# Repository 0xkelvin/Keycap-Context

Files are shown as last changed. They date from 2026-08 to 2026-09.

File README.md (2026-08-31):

# Keycap Context

Keycap Context is an open-source, local-first four-key controller for AI coding
agents. It turns Claude Code, Codex, Gemini CLI, Antigravity, OpenCode, and
generic agent prompts into a native macOS overlay you can answer from physical
keys.

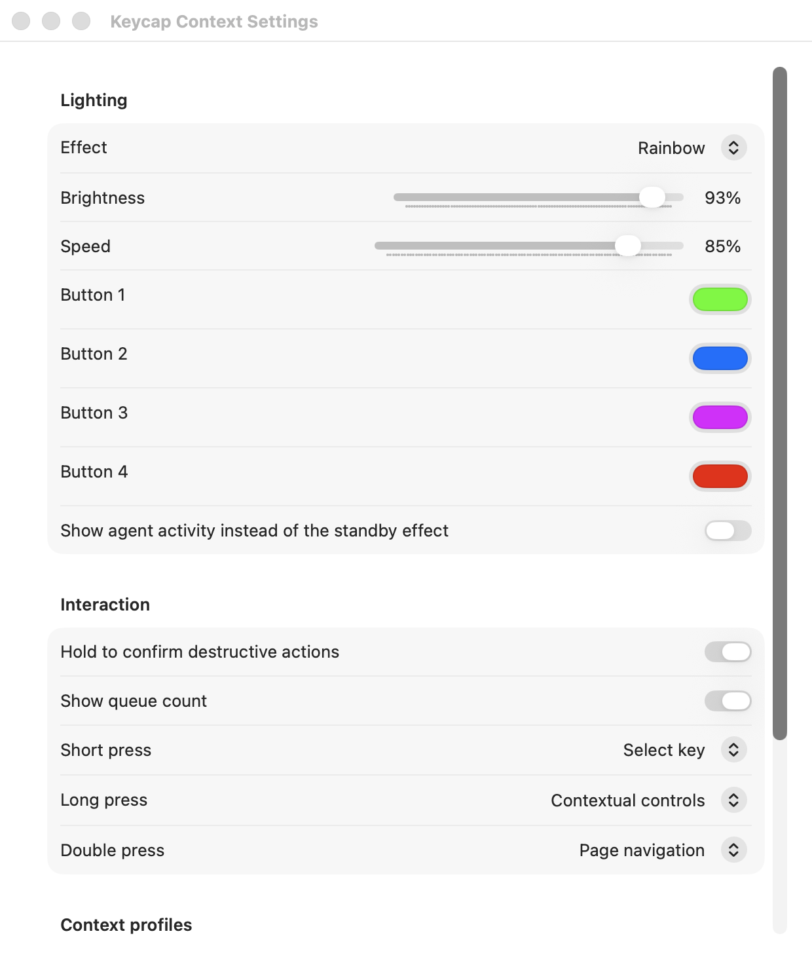
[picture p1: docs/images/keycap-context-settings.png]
Keycap Context lighting and interaction settings


## What it includes

- Zephyr firmware for a XIAO nRF54L15 Sense and Adafruit NeoKey 1x4
- Native macOS menu-bar host, choice overlay, lighting settings, and agent console
- Adapters for Claude Code, Codex, Gemini CLI, Antigravity, OpenCode, and generic JSON
- Short, long, and double-press gestures with RGB status and standby effects
- Four audio-reactive standby effects driven by the board's own microphone

## Quick start

```sh
./scripts/install.sh
```

For development without hardware:

```sh
cd host/macos
swift test
swift run keycap-host --demo
```

Firmware build:

```sh
west build -b xiao_nrf54l15/nrf54l15/cpuapp firmware
west flash
```

See [firmware setup](firmware/README.md), [architecture](docs/architecture.md),
and [adapter API](docs/http-api.md) for details.

## Hardware

Connect NeoKey `VIN/GND/SDA/SCL` to XIAO `3V3/GND/D4/D5`. Do not power NeoKey
VIN from both 3V3 and 5V.

## Privacy

The host is local-only and needs no macOS Accessibility permission. Adapters
reach it over loopback and authenticate with a per-install token.

The optional audio-reactive effects use the keypad's own microphone. Sound is
turned into four band levels on the device and drives its LEDs directly: no
audio and no derived measurement crosses the USB link, and the microphone is
left unpowered whenever another effect is selected. See [SECURITY.md](SECURITY.md).

## License

Apache-2.0

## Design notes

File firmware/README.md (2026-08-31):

# Firmware

The firmware targets the XIAO nRF54L15 Sense application core and talks to the
NeoKey's onboard seesaw controller at I2C address `0x30`.

## Build and flash

Use a recent Zephyr tree containing the XIAO nRF54L15 board definition, or the
corresponding nRF Connect SDK release:

```sh
west build -p always -b xiao_nrf54l15/nrf54l15/cpuapp firmware
west flash
```

The board's onboard SAMD11 debugger exposes the application console as a USB
CDC ACM serial port. The host opens that port at 115200 baud.

## Physical validation

1. Power the NeoKey from XIAO 3V3 and connect the common ground.
2. Connect NeoKey D/SDA to XIAO D4 and C/SCL to XIAO D5.
3. Flash firmware and open the CDC port at 115200 baud.
4. Confirm the `HELLO 3` line appears after reset.

### XIAO CMSIS-DAP serial recovery

The XIAO's onboard SAMD11 debug probe can leave its CDC serial bridge half-open
after flashing or resetting the nRF54L15: firmware output and button events
still reach the Mac, but commands sent to the board do not. The firmware then
correctly enters its amber host-watchdog state. Stop the host and fully unplug
and reconnect the board's USB cable to power-cycle the SAMD11 before testing.
If `KEEPALIVE` still does not produce `ALIVE`, diagnose or update the SAMD11
bridge rather than reflashing the nRF application repeatedly.
5. Send `LEDS FF0000,00FF00,0000FF,FFFFFF` and inspect the four pixels.
6. Press each key and confirm immediate ordered `BUTTON 1..4 DOWN`/`UP` events,
   followed by `GESTURE 1..4 SHORT`; also verify long and double presses.

## Local lighting

When no key is held, the four LEDs play a moving rainbow wave. Held keys take
immediate local priority: key 1 is green, key 2 blue, key 3 magenta, and key 4
orange. Multiple held keys light together, while unpressed keys turn off. The
local renderer refreshes at about 40 frames per second and therefore takes
visual priority over transient host LED commands.

The firmware intentionally uses the debugger's serial bridge for the first
prototype. A production PCB can expose native USB CDC from the application MCU
without changing the v1 protocol.

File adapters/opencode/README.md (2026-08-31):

# OpenCode adapter (experimental)

Install `keycap-plugin.ts` as a local OpenCode v2 plugin and add the matching
`@opencode-ai/plugin` beta dependency. It intercepts permission evaluation while
preserving OpenCode's native behavior on broker failure or overlay dismissal.
The v2 plugin API is beta, so pin the plugin package version to your OpenCode
release.

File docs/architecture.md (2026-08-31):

# Architecture

The product separates agent integrations, request policy, presentation, and
hardware. No adapter is allowed to write a number into whichever application
happens to have focus.

```text
Claude / Codex / generic CLI
            |
       agent adapter
            |
       local HTTP API
            |
     request broker/queue
       |            |
 macOS overlay   serial device
                     |
              XIAO nRF54L15
                     |
               NeoKey 1x4
```

## Request model

An adapter submits a request containing source/session metadata, the complete
question text, and one to four ordered choices. Labels and descriptions are
displayed verbatim. The broker never inserts a synthetic `Details` choice.

Only the first request is active. Later requests remain FIFO-queued. Resolving
the active request atomically removes it, replies to its adapter, and presents
the next request.

Dismissal follows the same lifecycle as a response but carries a cancellation
instead of a selected choice. The overlay's agent-specific **Handle in…** button
and its temporary Escape shortcut both cancel only the active request. Holding
Escape cannot drain the queue; the shortcut rearms after key release.

## Trust boundaries

- The HTTP listener binds only to `127.0.0.1`.
- Device input is semantic (`BUTTON 1 DOWN`), not USB HID keyboard input.
- A response is routed by request ID and cannot land in the focused editor.
- Accessibility permission is not required by the primary design.
- Escape is registered only while an overlay is visible and does not use a
  global event tap.
- Adapter content is untrusted display text and never interpreted as markup.

## Adapter levels

1. Native structured protocol: preferred for Codex App Server and agent SDKs.
2. Lifecycle hook: used by the initial Claude Code adapter.
3. Managed PTY parser: future compatibility fallback for other CLIs.

The hardware and broker API remain stable when adapters change.

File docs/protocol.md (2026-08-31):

# Device protocol

USB transport is an 8-N-1 serial stream at 115200 baud. Messages are ASCII,
newline terminated, and limited to 160 bytes. Unknown messages are ignored and
reported with `ERROR` where practical.

## Device to host

```text
HELLO 1 keycap-fw xiao-nrf54l15-sense
ALIVE
BUTTON <1..4> <DOWN|UP> <sequence>
GESTURE <1..4> <SHORT|LONG|DOUBLE> <sequence>
ERROR <code>
```

Example:

```text
BUTTON 2 DOWN 41
BUTTON 2 UP 42
```

Protocol-v1 hosts resolve a request on `BUTTON … DOWN`. Protocol-v2 firmware
emits `GESTURE` instead, after classifying short, long, and double presses.

The host resolves on `BUTTON … DOWN` only for a single-page, single-select,
non-destructive request. Paginated, multi-select, and hold-to-confirm requests
wait for the gesture so the long press that pages or confirms is not consumed
by an immediate selection.

### Framing errors

| Code | Meaning |
| --- | --- |
| `bad-command <line>` | The line did not parse as a command |
| `line-too-long` | The line exceeded 160 bytes; the tail is discarded |
| `rx-overflow` | The receive ring dropped bytes; the device resynchronizes |
| `i2c-write` | The NeoKey did not accept an LED update |
| `neokey-init` | The NeoKey is not addressable yet; the device keeps retrying |

`line-too-long` and `rx-overflow` both discard every byte up to the next
newline. A dropped newline would otherwise splice two commands into one
unparsable line, so the device forfeits one command to keep the stream framed.

## Host to device

```text
PING
KEEPALIVE
LEDS <RRGGBB>,<RRGGBB>,<RRGGBB>,<RRGGBB>
STATUS <IDLE|SUCCESS|ERROR|PAUSED>
STATUS WAITING <1..4> [RRGGBB]
LIGHTING <RAINBOW|WAVE|BREATHING|REACTIVE|AUDIO|STATIC|OFF> <0..100> <1..100> <RRGGBB,RRGGBB,RRGGBB,RRGGBB>
AGENTS <EMPTY|IDLE|WORKING|WAITING|DONE|ERROR|RISK>,<state>,<state>,<state>
```

The device replies to discovery `PING` with its `HELLO` line. After discovery,
the host sends `KEEPALIVE` every two seconds and the device replies `ALIVE`.
If acknowledgements stop for six seconds, the host first probes the existing
descriptor with `PING` and grants one further reply window. This avoids treating
a macOS sleep interval as a dead link and reopening the board's fragile
CMSIS-DAP bridge. Only an unanswered recovery probe closes the descriptor. A
later unsolicited `HELLO` requests full LED-state reinitialization.
The firmware also emits a fresh `HELLO` after the NeoKey finishes initializing.
Status or lighting commands can arrive while the I2C peripheral is still being
retried; this second handshake tells the host to replay them once the LEDs are
actually writable.
The host treats only `ALIVE` and `HELLO` as proof that the device is still
reading. Button and gesture lines are unsolicited and prove only the
device-to-host direction, so they do not refresh the liveness deadline; a link
that has gone half-open is closed and reopened instead of being held open by
key presses.
Once a serial candidate emits a valid Keycap protocol event, the host remembers
that path and does not rotate to unrelated USB modems (for example, monitor
control interfaces) after a transient heartbeat failure.

After five seconds without any valid host command, the device resumes its last
configured standalone lighting effect and repeats `HELLO` every two seconds
until the host answers. Amber is reserved for an explicit `PAUSED` status. The
first valid command clears the timeout, and the device sends one further
`HELLO` so the host re-asserts its current state.
`000000` turns a pixel off.
Color components are reduced by firmware before being written to the NeoKey to
limit brightness and USB current.

`LIGHTING` configures the device-local renderer. Brightness and speed are
percentages, and the four colors map to buttons 1 through 4. Local key-press
feedback takes visual priority over transient semantic status frames.

Protocol v3 adds `AGENTS`. Each comma-separated state maps directly to a
physical key: blue pulses while working, orange while waiting, green when work
completes, red on failure, pink for a destructive approval, dim blue for idle,
and black for an unassigned key. Approval `STATUS` frames temporarily take
priority over the agent console.

Example with three active choices:

```text
LEDS FFFFFF,FFFFFF,FFFFFF,000000
```

## Compatibility

The first integer in `HELLO` is the protocol major version. The current host
supports versions 1 through 3. Version 2 adds gestures and semantic status LEDs;
version 3 adds four-session agent states. Version 1 retains raw button events
and explicit `LEDS` commands. Hosts must
reject an unsupported major version rather than guessing message semantics.

## Audio-reactive lighting

Four effects share one capture from the board's own PDM microphone:
`LIGHTING AUDIO`, `LIGHTING SPECTRUM`, `LIGHTING PITCH` and `LIGHTING TEMPO`.

### AUDIO: level meter

`LIGHTING AUDIO` turns the four keys into a single level meter. Analysis happens entirely on the device: the keypad
reports no audio, no level and no derived measurement to the host. The link
could not carry it in any case, since 16 kHz mono PCM is roughly 32 kB/s against
a 11.5 kB/s serial budget.

The command carries no new fields. Every lit key shares one colour that walks
the rainbow wheel at `speed`, the same rate the `RAINBOW` effect uses.
`brightness` caps the meter. The four `RRGGBB` values are unused by this effect.

Loudness fills the keys as one bar, so louder sound lights more keys rather than
different ones:

| Level | Key 1 | Key 2 | Key 3 | Key 4 |
| --- | --- | --- | --- | --- |
| silence | dim ember | off | off | off |
| quiet | rising | off | off | off |
| moderate | full | rising | off | off |
| loud | full | full | rising | off |
| peak | full | full | full | full |

The meter normalises against its own rolling noise floor and peak, so it uses
the whole bar at any volume while a room's noise floor holds it nearly closed.
Rise is immediate and the fall is eased over roughly 300 ms, so it reads like a
VU needle rather than a strobe. Silence leaves the dim ember on the first key,
still cycling colour, so the device never looks dead.

### SPECTRUM: four bands, four colours

`LIGHTING SPECTRUM` gives each key its own frequency band and its own colour
from the profile, so the keys move independently and show what the music is made
of rather than how loud it is. `speed` is unused; `brightness` caps the display.

| Key | Band | Content |
| --- | --- | --- |
| 1 | up to ~170 Hz | kick and bass |
| 2 | ~170-700 Hz | body, low vocals |
| 3 | ~700 Hz-1.8 kHz | presence |
| 4 | above ~1.8 kHz | cymbals and air |

Each band normalises against its own floor and peak, so a quiet treble band does
not sit dark merely because the bass is loud. Every key keeps the same dim ember
in silence.

### PITCH: colour from content

`LIGHTING PITCH` gives all four keys one hue chosen by where the sound's energy
sits, and brightens them together with its loudness. Red is bass, green the
mids, violet the treble, so the colour reflects what the music is made of rather
than advancing on a timer. `speed` and the key colours are unused;
`brightness` caps the display.

The hue is a centroid over raw band energy with a fixed tilt, not over the
normalised band levels: per-band auto-gain drives every band to full whenever it
is near its own recent maximum, so the normalised levels reach 255 together and
preserve no balance to take a centroid of. The tilt offsets the steep falloff of
musical energy with frequency, which would otherwise pin the hue at the bass
end. Silence holds the last hue rather than snapping back to red.

### TEMPO: colour that advances with the beat

`LIGHTING TEMPO` fills the keys with loudness exactly as `AUDIO` does, but takes
its hue from the beat count rather than the clock, stepping one eighth of the
wheel on every bass transient. A full turn is eight beats, two bars of four, so
the colour returns to where it started on a musical boundary and a slow track
drifts where a fast one races. `speed` and the key colours are unused.

A beat is bass that is clear of its own noise floor, above its own rolling
average, **and rising against the previous frame**. The rise is what separates a
transient from mere loudness: a sustained bass note sits above its average for
as long as it lasts and would otherwise retrigger on every frame. Beats are
measured on raw band energy, since per-band auto-gain pins a loud passage at
full scale and leaves a kick no headroom to stand out in.

### Microphone power

The microphone is powered only while `AUDIO`, `SPECTRUM`, `PITCH` or `TEMPO` is the
selected effect and the standby lane is visible, and only while there is
something to listen to: after about ten minutes with no dynamic range in the
signal the device powers the regulator down, falls back to a dim standby
effect, and waits. Pressing any key wakes it, as does a fresh `LIGHTING`
command. A selected effect therefore holds the microphone live when music is
playing rather than for as long as the keypad is switched on.

Silence is judged as a ratio, not an absolute level: music holds its peak many
times its noise floor while a room's own noise stays within a factor of two of
it. A fixed threshold would never fire in one room and fire constantly in
another. Selecting a non-audio effect, an approval overlay, or agent
status all switch the microphone's regulator off, so an unselected microphone is
unpowered rather than merely ignored.

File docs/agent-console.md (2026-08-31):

# Agent Console

Agent Console assigns up to four recent agent sessions to the four physical
keys. Waiting sessions are protected from replacement; when all slots are full,
the oldest idle or completed session is replaced first.

## States

Settings defaults to the selected four-key standby lighting effect. Enable
**Show agent activity instead of the standby effect** to display these states
on protocol-v3 hardware while no approval overlay is visible.

| State | LED | Meaning |
| --- | --- | --- |
| Working | Pulsing blue | Agent is reasoning or executing tools |
| Waiting | Pulsing orange | Agent needs a decision |
| Destructive | Pulsing pink | Decision can modify or remove data |
| Completed | Green | Completed activity has not been acknowledged |
| Failed | Pulsing red | Agent or tool failed |
| Idle | Dim blue | Session is assigned but inactive |

The menu-bar **Agent Console…** window shows source, project, current state,
focus/interrupt/resume/cancel controls, and the last 500 local status, approval,
resolution, and control events. The history contains summaries—not secrets or
complete terminal transcripts—and is stored in Application Support.

Persistent adapters drain control commands from the local HTTP API. The Codex
App Server bridge maps interrupt/cancel to its native `turn/interrupt` request.
Hook-only adapters receive the status and approval features but cannot interrupt
a tool that is already running; the command remains available to a future
persistent bridge.

## Context profiles

When a key has no assigned agent, a short press may execute the first profile
matching the frontmost application's bundle identifier and project rule.
Actions can focus or interrupt an agent, open an HTTP(S) URL, or run a local
shell command. Interrupts and shell commands always require confirmation.
Settings renders the four actions before assignment so workflows can be
reviewed without executing them.

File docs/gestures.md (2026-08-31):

# Hardware gestures

Firmware protocol v2 delays a short press for 280 ms so it can distinguish a
double press. A long press fires after 600 ms. Holding a key produces one event.

| Gesture | Action |
| --- | --- |
| Short press 1–4 | Select the visible choice, or toggle it in multi-select |
| Double press 1 | Previous page |
| Double press 4 | Next page |
| Long press 1 | Previous page |
| Long press 2 | Clear multi-select choices |
| Long press 3 | Hand the request back to the agent |
| Long press 4 | Submit multi-select, otherwise next page |

When no approval overlay is visible, protocol-v3 keys control their assigned
agent session:

| Gesture | Agent-console action |
| --- | --- |
| Short press | Focus the originating terminal application |
| Long press | Request an interrupt and cancel any queued approval |
| Double press | Mark completed work as read |

Agent focus begins immediately on the first physical button-down, before the
280 ms gesture-classification window. The later short event is consumed; a
continued hold or second press still performs its long/double action. On a
multi-monitor Mac, focusing raises the terminal's most recently used window on
the display where that window already lives—it does not move windows between
displays.

Single-page, single-choice approval overlays resolve from the debounced
`BUTTON DOWN` event immediately. The delayed gesture event is consumed by the
host so it cannot affect the next queued overlay or an Agent Console assignment.
Paginated, multi-select, and destructive hold-to-confirm requests wait for the
gesture instead, because an immediate selection would consume the long press
that pages or confirms.

Protocol-v1 firmware remains compatible and resolves on `BUTTON … DOWN`.

LED states are semantic in protocol v2: dim blue is idle, agent-colored keys
are waiting choices, green is success, red is error, and amber is paused. If no
host command arrives for five seconds, firmware resumes the last standalone
lighting effect while continuing to advertise for reconnection.

Protocol-v3 idle LEDs run the selected standby lighting effect by default.
Settings can instead show agent state: blue working, orange waiting, green
completed, red failed, pink destructive approval, dim blue idle, and off when
no session is assigned.

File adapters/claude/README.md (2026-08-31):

# Claude Code adapter

The adapter uses two documented Claude Code lifecycle hooks:

- `PermissionRequest` for allow/always-allow/deny decisions
- `PreToolUse` filtered to `AskUserQuestion` for exact multiple-choice input
- `PreToolUse` filtered to `ExitPlanMode` for plan approval

The hook posts to the local broker and blocks until a physical or overlay
selection resolves the request. If the broker cannot be reached, it emits no
decision and Claude retains its normal terminal interaction.

Choose **Handle in Claude** in the overlay or press Escape to dismiss the active
request without making a selection. The broker releases the waiting hook, which
emits no decision so Claude presents its normal terminal interaction.

`AskUserQuestion` is excluded from the generic `PermissionRequest` bridge. This
prevents Claude's raw question payload from being queued as a second permission
overlay after a question is handed back to the terminal.

## Configure

1. Start `keycap-host`.
2. Copy the entries in `settings.fragment.json` into the existing `hooks`
   object in `~/.claude/settings.json`.
3. Replace `/ABSOLUTE/PATH/TO` with this repository's absolute path.
4. Run `/hooks` in Claude Code and verify both entries.

Do not replace an existing `hooks` object wholesale. Merge the two event arrays
with any hooks already configured.

Single-choice, multi-select, and batches of several questions are supported.
Multi-select uses an explicit Submit button in the overlay; protocol-v2 hardware
uses a long press on key 4 to submit.

## How an answered question is returned

The hook allows the call with the answers filled into `updatedInput`.
`AskUserQuestion` honours a pre-filled `answers` field and returns it without
prompting, so the question is not asked again in the terminal.

Handing the overlay back instead returns nothing at all, which lets Claude Code
prompt in the terminal as usual.

Denying the call and carrying the answers in `permissionDecisionReason` also
works, but Claude Code renders a blocked call as an error, which reads like a
failure. Measured against a live broker, the allowed call returns in the same
second the keypad resolves the overlay; a terminal prompt instead shows up as a
gap of tens of seconds.

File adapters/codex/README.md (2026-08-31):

# Codex adapter

The initial adapter uses Codex's documented `PermissionRequest` lifecycle hook.
It displays the tool description and complete JSON input, then offers the two
decisions the hook API can currently return safely: Allow and Deny.

## Configure

1. Start `keycap-host`.
2. Merge `hooks.fragment.json` into `~/.codex/hooks.json` and replace the
   absolute-path placeholder.
3. Open `/hooks` in Codex and explicitly review/trust the new hook.

If the broker is unavailable, the hook emits no decision and Codex presents
its normal terminal approval prompt.

Choose **Handle in Codex** in the overlay or press Escape to dismiss the active
request without making a selection. The hook emits no decision, returning the
approval to Codex's terminal UI.

## Rich adapter

`app_server_bridge.py` is a transparent stdio proxy for clients that normally
launch `codex app-server`. Configure the client to launch:

```sh
python3 /ABSOLUTE/PATH/TO/adapters/codex/app_server_bridge.py codex app-server
```

The proxy routes command and file approvals—including `acceptForSession`—and
`item/tool/requestUserInput` through Keycap. If the user chooses **Handle in
Codex**, the original server request is forwarded to the parent client so its
normal UI remains authoritative. Secret and free-form questions also pass
through unchanged.

The bridge uses the App Server schema generated by the installed Codex version;
WebSocket transport remains experimental upstream and is intentionally outside
this stdio proxy.

The hook does not invent an Always Allow option because Codex currently rejects
permission updates from `PermissionRequest` hooks.

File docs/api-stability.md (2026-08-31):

# API stability

The loopback broker API is versioned under `/v1`. Additive JSON fields are
allowed within v1; existing fields, response meanings, and HTTP lifecycle
semantics are stable. Breaking changes require a new path such as `/v2`.

Device protocol major versions are announced by `HELLO`. The host supports
majors 1 and 2 and must reject unknown majors. New optional commands may be
added to protocol 2, but existing command grammar and gesture meanings remain
stable.

Settings use a `schemaVersion`. Unknown or malformed settings fall back to safe
defaults, while the previous valid file is retained as `settings.json.previous`.
Adapters must preserve the native agent UI whenever the broker is unavailable,
returns cancellation, or rejects a request.

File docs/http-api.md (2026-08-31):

# Local HTTP API

Keycap Context listens only on `127.0.0.1`. The default port is `47821`; set
`KEYCAP_PORT` or pass `--port` to the host, and set `KEYCAP_BROKER_URL` in
adapters when using a different port.

## Authentication

Loopback binding proves only that the caller is on this machine. It does not
distinguish a trusted adapter from any other local process, nor from a web page
the user is visiting: a CORS-simple `POST` from a page reaches the broker with a
loopback `Host` header like any other client. Every request is therefore
authenticated.

On first launch the host writes a 32-byte random token, owner-readable only, to
`~/Library/Application Support/Keycap Context/token` (override with
`KEYCAP_TOKEN_PATH`). Adapters present it as `Authorization: Bearer <token>` or
`X-Keycap-Token: <token>`; the bundled adapters read the file automatically, and
`KEYCAP_TOKEN` overrides it.

This secret protects against other machine accounts and, together with the
fetch-metadata checks, browser pages. It is not a sandbox boundary against an
untrusted process already running as the same macOS user: that process can read
the same owner-readable token as an adapter.

```sh
curl -s -H "Authorization: Bearer $(cat ~/Library/Application\ Support/Keycap\ Context/token)" \
  http://127.0.0.1:47821/health
```

The broker answers `401 Unauthorized` for a missing or wrong token and `403
Forbidden` for a non-loopback `Host` header or for any request carrying browser
fetch metadata (`Origin`, or `Sec-Fetch-Site` other than `none`). Adapters treat
both as "broker unavailable" and fall back to the agent's own terminal prompt,
so a stale token degrades safely rather than blocking an agent.

## Endpoints

- `GET /health` returns broker, queue, pause, agent, and device health.
- `GET /v1/capabilities` reports API and device protocol capabilities.
- `POST /v1/requests/wait` submits an `AgentRequest` and holds the response
  until it is selected or cancelled.
- `DELETE /v1/requests/{id}` cancels one pending request.
- `POST /v1/sessions/cancel` with `{"session":"..."}` cancels all requests
  owned by a session.
- `POST /v1/sessions/status` reports `working`, `waiting`, `completed`, `failed`,
  or `idle` activity for a session.
- `GET /v1/sessions` returns the persistent four-key session assignments.
- `DELETE /v1/sessions/{session}` unassigns a session from its physical key.
- `POST /v1/sessions/control` queues `focus`, `interrupt`, `resume`, `cancel`,
  or `markRead` for a session.
- `GET /v1/sessions/{session}/commands` atomically drains pending controls for
  a persistent adapter bridge.
- `GET /v1/history` returns the bounded local approval/control audit history.

The broker rejects malformed requests with `422`, duplicate IDs with `409`,
new requests while paused with `503`, and requests beyond the 64-entry queue
limit with `429`. A disconnected waiting client is
removed from the queue automatically.

The server authenticates every request, validates the HTTP `Host` header as
loopback-only, refuses browser-originated requests, and bounds request and field
sizes before presentation.

Requests support one to sixteen choices, optional `allowsMultiple`, optional
`progress` (`current` and `total`), optional `timeoutSeconds`, and an optional
six-digit `accentColor`. Multi-select responses include ordered `choiceIds`;
single-select responses retain the backward-compatible `choiceId` field.
Requests may set `risk` to `destructive` to activate hold-to-confirm behavior.
Requests may also provide `clientApp`, a macOS bundle identifier used only to
focus the originating terminal. The host never accepts remote network clients.

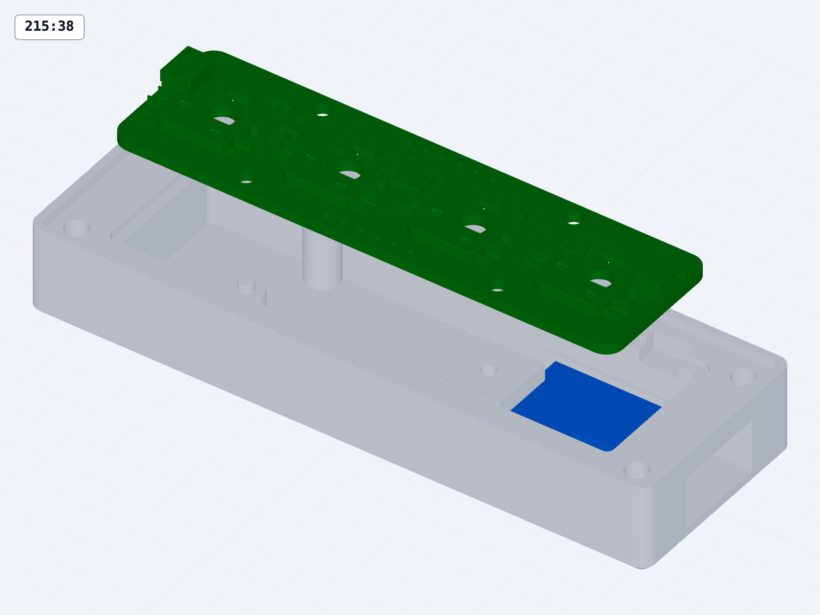
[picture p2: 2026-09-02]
cad/renders/09-boards-in-tray.png

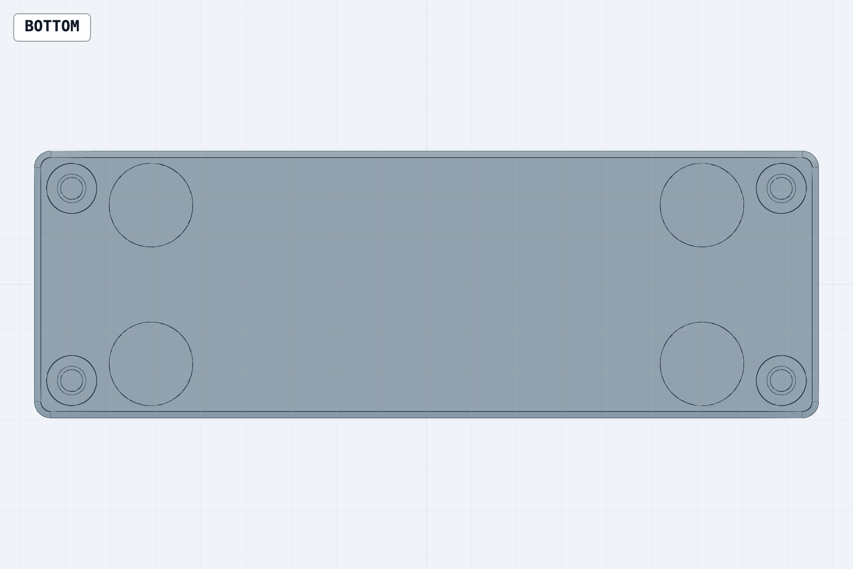
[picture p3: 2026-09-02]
cad/renders/05-underside.png

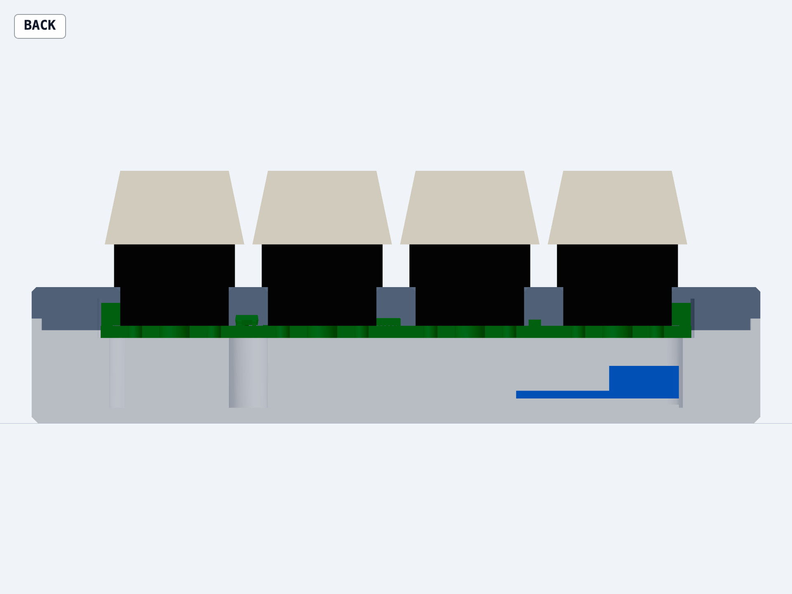
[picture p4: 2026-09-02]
cad/renders/07-cutaway-section.png

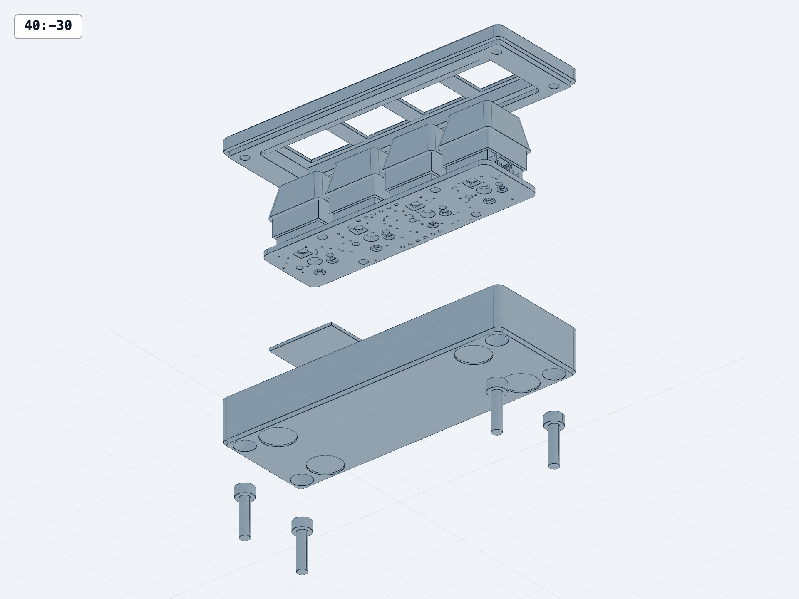
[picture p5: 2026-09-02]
cad/renders/11-plate-underside.png

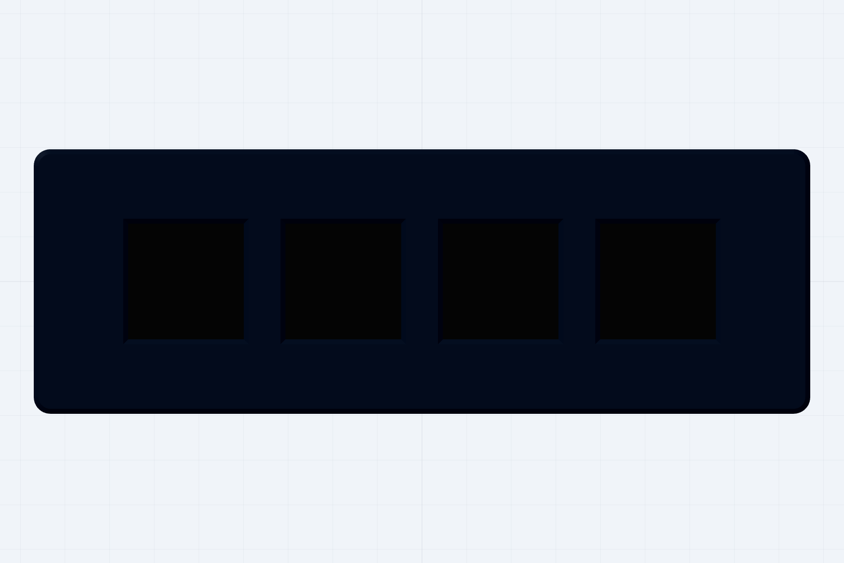
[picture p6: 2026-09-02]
cad/renders/03-plate-top.png

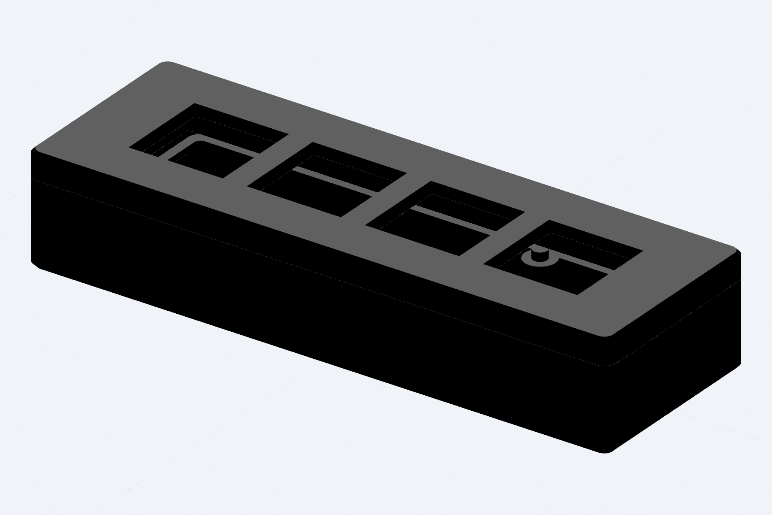
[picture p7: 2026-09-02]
cad/renders/colourways/ink.png

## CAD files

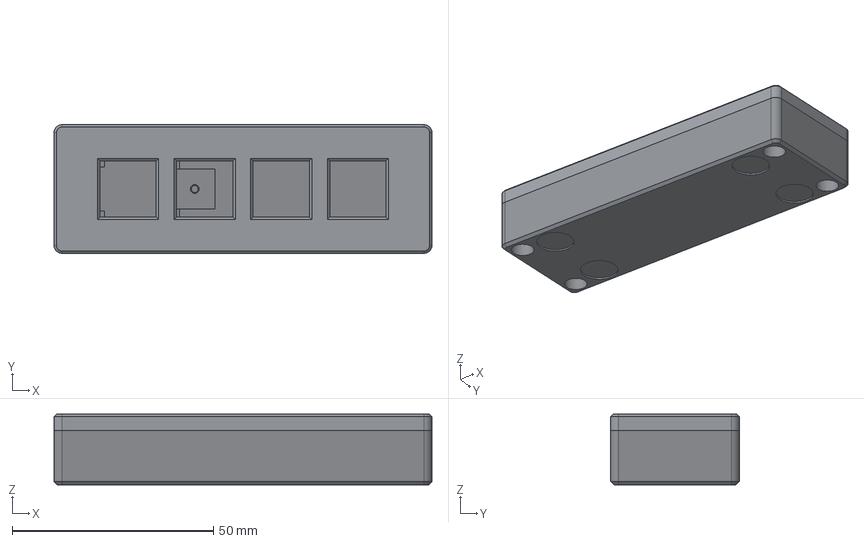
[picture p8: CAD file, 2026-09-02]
cad/keycap_case.step
94.0 x 32.0 x 17.6 mm
tray
plate
xiao_clamp

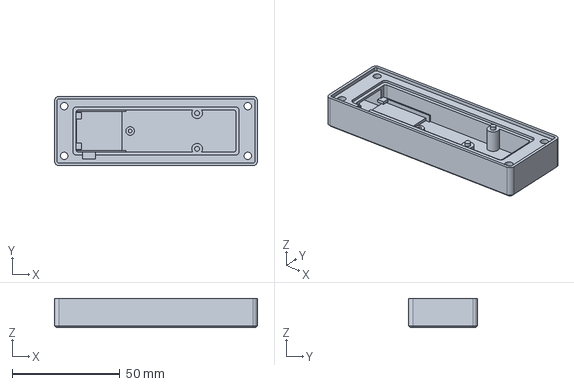
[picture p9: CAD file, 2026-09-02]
cad/print/tray.step
94.0 x 32.0 x 13.5 mm

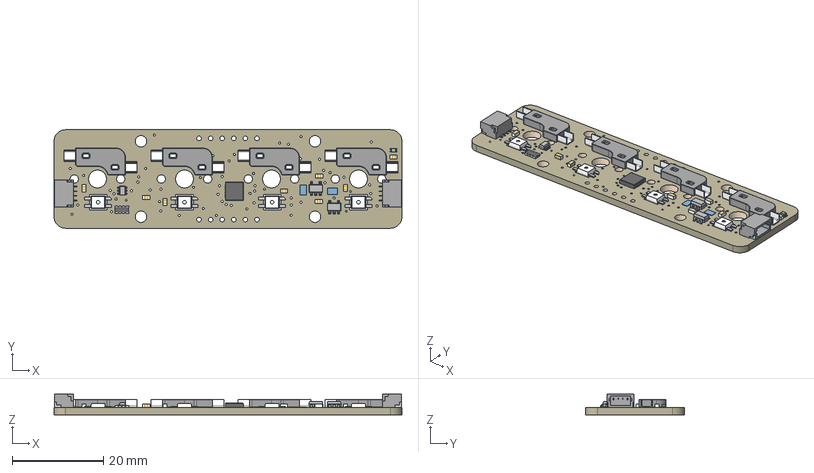
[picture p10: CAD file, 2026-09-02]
cad/reference/neokey_1x4_qt_4980.step
76.2 x 21.6 x 4.53 mm
Board
KAILH_SOCKET x 4
WS2812B_SK6812E x 4
10K x 8
10uF x 2
AP2112K-3.3
10K_1
BSS138
STEMMA_I2C_QT x 2
GREEN
ATSAMD09D14A-MU
74AHCT1G125DBV

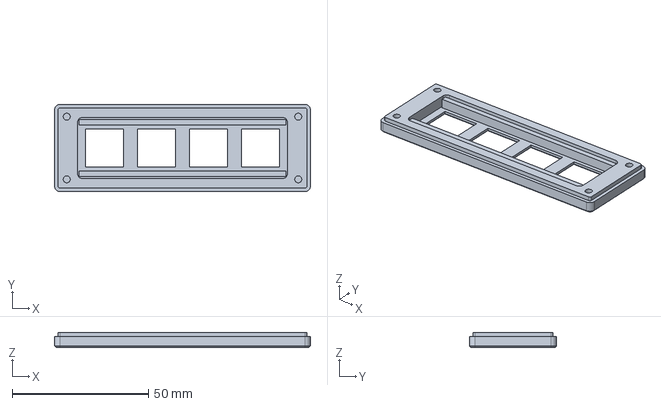
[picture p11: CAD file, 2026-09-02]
cad/print/plate.step
94.0 x 32.0 x 5.57 mm

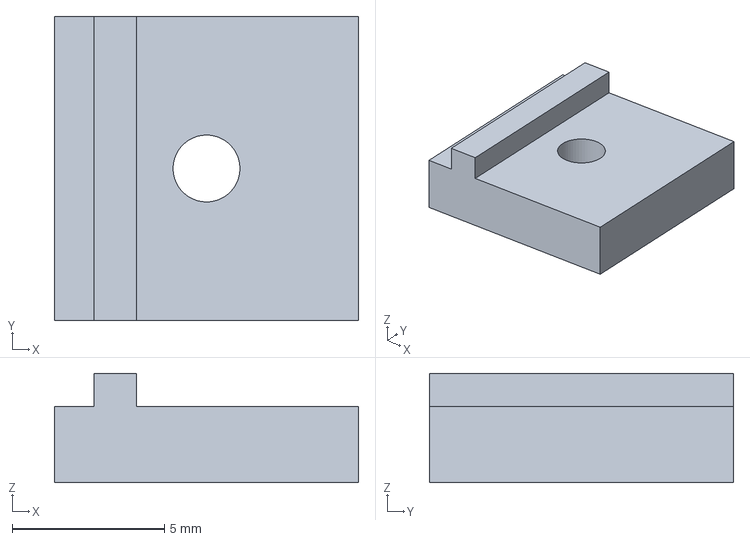
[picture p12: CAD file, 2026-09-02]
cad/print/xiao_clamp.step
10.0 x 10.0 x 3.60 mm

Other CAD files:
cad/print/stl/plate.3mf
cad/print/stl/plate.stl
cad/print/stl/tray.3mf
cad/print/stl/tray.stl
cad/print/stl/xiao_clamp.3mf
cad/print/stl/xiao_clamp.stl

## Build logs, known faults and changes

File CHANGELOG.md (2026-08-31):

# Changelog

## Unreleased

### Added

- Added an `AUDIO` lighting effect: the four keys become one level meter driven
  by the board's PDM microphone, sharing a single colour that cycles the rainbow
  at the profile speed. Loudness fills the keys in order, normalised against a
  rolling noise floor so the whole bar is used at any volume, with an immediate
  rise, an eased fall, and a dim ember left on the first key in silence.
  Analysis runs entirely on the device; no audio or derived measurement crosses
  the serial link, and the microphone's regulator is switched off whenever
  neither audio effect is selected.
- Added a `SPECTRUM` lighting effect sharing the same capture: each key takes
  its own frequency band and its own colour, bass on key one through treble on
  key four, with each band normalised independently.
- Added a `PITCH` lighting effect sharing the same capture: all four keys take
  one hue from where the sound's energy sits, red for bass through violet for
  treble, brightening together with loudness. The hue holds through silence
  rather than resetting between tracks.
- Raised the NeoKey I2C bus to fast mode, quartering the time the main loop
  spends blocking on each LED frame.

- The microphone now sleeps after about ten minutes with nothing playing: the
  regulator is switched off, the keys fall back to a dim standby effect, and a
  key press wakes it. Silence is judged by how little dynamic range the signal
  has relative to its own noise floor, so the test does not depend on a room's
  absolute noise level.

- Added a `TEMPO` lighting effect: the level meter with a colour that steps one
  eighth of the wheel on every bass transient, so the palette advances with the
  music rather than with a clock.

- The overlay now says which gesture finishes the request. Multi-select shows
  how to submit and clear, and a paginated request how to page, alongside the
  hold-to-confirm hint destructive requests already had. The hints follow the
  configured gesture mapping, so a remapped long press earns no hint rather
  than a wrong one.

### Fixed

- `keycap_audio_analyzer_init` cleared only its channels, leaving the beat
  count, hue, quiet countdown and bass history holding whatever was previously
  on the audio thread's stack.

- A short press on an assigned key no longer re-activates its terminal when that
  terminal is already frontmost. This was the cause of questions appearing to
  repeat: each activation redraws whatever prompt the terminal is showing, and
  an audio effect invites exactly the run of presses that triggers it.

- An unrecognised lighting effect in the settings file no longer discards every
  other preference. A strict decoder failed the whole file, so a host without a
  newer effect silently reverted brightness, colours, gestures and profiles to
  their defaults.

### Fixed

- A slow NeoKey/I2C startup no longer leaves all four LEDs stuck on the amber
  paused frame. The firmware announces itself again after LED initialization,
  causing the host to replay status and the selected standby lighting profile.
- Serial configuration failures now close their file descriptor, and stale
  immediate-press gesture state is cleared across device reconnects.
- Serial autodetection now rotates through every USB modem candidate after a
  failed handshake instead of retrying the same unrelated debug port forever.
- Malformed persisted lighting values are normalized before the four-key
  settings UI reads them, avoiding an out-of-range crash on edited settings.
- Idle agent switching now focuses on the initial button-down instead of after
  the double-press delay, and no longer raises every terminal window across a
  multi-monitor desktop.
- The macOS serial host now clears inherited modem/flow-control flags and
  flushes stale bytes before discovery. A CMSIS-DAP port could otherwise remain
  half-open: buttons reached the host, but lighting and heartbeat commands did
  not reach the board. Device health now becomes connected only after a valid
  firmware `HELLO`, so an LG monitor-control modem cannot report as a Keycap.
- After any valid Keycap event, serial discovery now remains affined to that
  device and will not rotate onto an external monitor's control modem during a
  one-way CMSIS-DAP bridge failure.
- Wake recovery now probes the existing serial descriptor before closing it,
  avoiding the SAMD11 reopen path that wedges after macOS sleep. If the host is
  unavailable, firmware continues the last standby effect instead of latching
  all four LEDs amber.
- Reinstalling or packaging now replaces adapter directories instead of
  merging stale files, and excludes generated Python caches and test fixtures.
- Multi-select requests now offer a Submit control. The button had been placed
  in the hold-to-confirm branch, so a multi-select question could only be
  answered with a hardware long press, and destructive requests showed a
  redundant disabled `Submit 0` beside `Confirm selection`.
- Paginated single-select requests no longer resolve from `BUTTON … DOWN`. The
  immediate press consumed the long press that pages, so requests with five to
  sixteen choices exposed only their first four options on hardware.
- The firmware resynchronizes the serial stream after the receive ring drops
  bytes, and keeps draining the ring while the NeoKey is still initializing.
  Blocking retries had overflowed the ring and spliced host commands together
  (`PING` + `PING` arriving as `PIPING`).
- Overlay choices accept the first mouse click while another application is
  frontmost.
- The keys no longer stay amber after the host watchdog fires. The fail-safe
  had latched the flag that suppresses the standby effect, and only a `STATUS`
  command cleared it -- which the host sends on state changes only, so a
  recovered link stayed amber until the board was unplugged.
- The device repeats `HELLO` every two seconds while the host is unreachable.
  The single announcement was emitted during the outage that triggered it, so
  losing that one line left both sides waiting for each other.
- Added `keycap_console_ready` and `keycap_serial_error` beside the existing
  `keycap_neokey_status` probe word, so a board whose console never comes up can
  still report where bring-up stopped over SWD.
- A failed console bring-up no longer ends `main()`. Returning left the device
  permanently silent with the NeoKey holding its last frame, recoverable only by
  a power cycle; the device now retries until the console is ready.
- The host no longer treats unsolicited button and gesture traffic as proof the
  device is still listening. Only replies to its own `PING`/`KEEPALIVE` count,
  so a half-open link is now detected and reconnected within six seconds
  instead of being held open by the user pressing keys.

### Security

- The local HTTP API authenticates every request with a per-install token
  written owner-readable to Application Support, and refuses requests carrying
  browser fetch metadata. A loopback `Host` header alone had been sufficient to
  read the approval history or raise a spoofed approval overlay.
- Token permission changes now fail closed, browser `Origin: null` requests are
  rejected, and the installer refuses unsafe root/home removal targets.

### Added

- Added the Agent Console with four persistent agent/session slots, status LEDs,
  terminal focus, interrupts, resume/cancel commands, and local audit history.
- Added protocol v3 `AGENTS` rendering and two additional firmware Ztests.
- Added firmware framing tests and a CI job that runs the Zephyr ztests.
- Added an Antigravity CLI plugin with native fallback and lifecycle reporting.
- Added context-aware application/project profiles and workflow preview.
- Added session status, control, command-polling, session-list, and history APIs.
- Added persisted lighting profiles and a macOS settings window.
- Added rainbow, wave, breathing, reactive, static, and off lighting modes.
- Added adjustable brightness, speed, and per-key colors.
- Added hold-to-confirm behavior for requests marked destructive.
- Added a diagnostics export and connected firmware/protocol information.

## 0.4.0

- Added protocol-v2 gestures, semantic LEDs, richer Codex/Claude adapters,
  cancellation cleanup, pagination, multi-select, installer, and CI.

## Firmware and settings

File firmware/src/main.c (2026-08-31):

/* SPDX-License-Identifier: Apache-2.0 */
#include "neokey.h"
#include "protocol.h"
#include "gesture.h"
#include "lighting.h"
#include "line_reader.h"
#include "audio.h"

#include <errno.h>
#include <string.h>
#include <zephyr/device.h>
#include <zephyr/devicetree.h>
#include <zephyr/drivers/uart.h>
#include <zephyr/irq.h>
#include <zephyr/kernel.h>
#include <zephyr/sys/ring_buffer.h>

#define NEOKEY_ADDRESS 0x30
#define DEBOUNCE_SAMPLES 2
#define HOST_WATCHDOG_MS 5000u
#define HOST_HELLO_RETRY_MS 2000u
#define NEOKEY_RETRY_SLICE_MS 50u
#define NEOKEY_RETRY_SLICES 20u

static const struct device *const console = DEVICE_DT_GET(DT_CHOSEN(zephyr_console));
static const struct device *const i2c = DEVICE_DT_GET(DT_ALIAS(neokey_i2c));
RING_BUF_DECLARE(serial_rx, 512);

/* Set from the receive interrupt when the ring cannot hold an incoming chunk.
 * The dropped bytes may include a newline, so the main loop must discard the
 * damaged region rather than parse two spliced commands as one.
 */
static volatile bool serial_rx_overflow;
static struct keycap_line_reader line_reader;

/* Set once the microphone has been powered down for want of anything to
 * listen to. Cleared by a key press or by the host changing the lighting.
 */
static bool audio_asleep;

/* Kept visible for probe-based bring-up and field diagnostics.
 *
 * When the console does not come up there is no way to report a fault, so
 * bring-up state is recorded in RAM where a debugger can read it:
 *
 *   arm-zephyr-eabi-nm build/zephyr/zephyr.elf | grep keycap_
 *   openocd ... -c "halt" -c "mdw <address> 1" -c "resume"
 *
 * keycap_console_ready  1 once the console device reports ready
 * keycap_serial_error   0 once the receive callback is installed
 * keycap_neokey_status  0 once the NeoKey answers on I2C
 */
volatile int keycap_neokey_status = -EINPROGRESS;
volatile int keycap_console_ready = -1;
volatile int keycap_serial_error = -EINPROGRESS;

static void serial_rx_callback(const struct device *device, void *user_data)
{
	ARG_UNUSED(user_data);
	uint8_t bytes[32];

	uart_irq_update(device);
	if (!uart_irq_rx_ready(device)) {
		return;
	}

	int count;
	while ((count = uart_fifo_read(device, bytes, sizeof(bytes))) > 0) {
		if (ring_buf_put(&serial_rx, bytes, (uint32_t)count) <
		    (uint32_t)count) {
			serial_rx_overflow = true;
		}
	}
}

static bool take_rx_overflow(void)
{
	unsigned int key = irq_lock();
	bool overflowed = serial_rx_overflow;

	serial_rx_overflow = false;
	irq_unlock(key);
	return overflowed;
}

static int serial_rx_start(void)
{
	keycap_console_ready = device_is_ready(console) ? 1 : 0;
	if (keycap_console_ready != 1) {
		return -ENODEV;
	}

	int error = uart_irq_callback_user_data_set(console, serial_rx_callback, NULL);
	keycap_serial_error = error;
	if (error != 0) {
		return error;
	}
	uart_irq_rx_enable(console);
	return 0;
}

static void serial_write(const char *text)
{
	while (*text != '\0') {
		uart_poll_out(console, *text++);
	}
}

static void send_hello(void)
{
	serial_write("HELLO 3 keycap-fw xiao-nrf54l15-sense\n");
}

static int show_status(struct neokey *keys, enum keycap_status status,
		       uint8_t active_choices, const struct keycap_rgb *accent)
{
	struct keycap_rgb colors[KEYCAP_LED_COUNT] = {0};
	struct keycap_rgb color = {0};
	uint8_t count = KEYCAP_LED_COUNT;

	switch (status) {
	case KEYCAP_STATUS_IDLE:
		color = (struct keycap_rgb){.red = 0, .green = 12, .blue = 28};
		break;
	case KEYCAP_STATUS_WAITING:
		color = accent != NULL ? *accent :
			(struct keycap_rgb){.red = 90, .green = 120, .blue = 255};
		count = active_choices;
		break;
	case KEYCAP_STATUS_SUCCESS:
		color = (struct keycap_rgb){.red = 0, .green = 255, .blue = 40};
		break;
	case KEYCAP_STATUS_ERROR:
		color = (struct keycap_rgb){.red = 255, .green = 0, .blue = 0};
		break;
	case KEYCAP_STATUS_PAUSED:
		color = (struct keycap_rgb){.red = 255, .green = 80, .blue = 0};
		break;
	}

	for (uint8_t index = 0; index < count && index < KEYCAP_LED_COUNT; ++index) {
		colors[index] = color;
	}
	return neokey_set_leds(keys, colors);
}

static bool process_line(struct neokey *keys, bool keys_ready,
			 struct keycap_lighting_profile *lighting,
			 enum keycap_agent_state agents[KEYCAP_LED_COUNT],
			 bool *agents_active, bool *status_active, char *line)
{
	struct keycap_command command;
	if (!keycap_protocol_parse(line, &command)) {
		serial_write("ERROR bad-command ");
		serial_write(line);
		serial_write("\n");
		return false;
	}

	if (command.type == KEYCAP_COMMAND_PING) {
		send_hello();
		return true;
	}
	if (command.type == KEYCAP_COMMAND_KEEPALIVE) {
		/* The acknowledgement lets the host detect a stale macOS serial
		 * descriptor after the board has been unplugged and reconnected.
		 */
		serial_write("ALIVE\n");
		return true;
	}
	if (!keys_ready) {
		/* The NeoKey is not addressable yet. Keep the framing healthy and
		 * stay silent; the host resends state after the next HELLO.
		 */
		return true;
	}

	if (command.type == KEYCAP_COMMAND_LEDS) {
		if (neokey_set_leds(keys, command.leds) != 0) {
			serial_write("ERROR i2c-write\n");
		}
	} else if (command.type == KEYCAP_COMMAND_STATUS) {
		if (show_status(keys, command.status, command.active_choices,
				command.has_status_color ? &command.status_color
							 : NULL) != 0) {
			serial_write("ERROR i2c-write\n");
		} else {
			*agents_active = false;
			*status_active = command.status != KEYCAP_STATUS_IDLE;
		}
	} else if (command.type == KEYCAP_COMMAND_LIGHTING) {
		*lighting = command.lighting;
		/* Choosing an effect is an explicit request to listen again. */
		audio_asleep = false;
	} else if (command.type == KEYCAP_COMMAND_AGENTS) {
		memcpy(agents, command.agents, sizeof(command.agents));
		*agents_active = true;
		*status_active = false;
	}
	return true;
}

static void pump_serial(struct neokey *keys, bool keys_ready,
			struct keycap_lighting_profile *lighting,
			enum keycap_agent_state agents[KEYCAP_LED_COUNT],
			bool *agents_active, bool *status_active,
			uint32_t *last_host_command, bool *host_timed_out)
{
	uint8_t byte;

	if (take_rx_overflow()) {
		keycap_line_reader_resynchronize(&line_reader);
		serial_write("ERROR rx-overflow\n");
	}

	while (ring_buf_get(&serial_rx, &byte, 1) == 1) {
		switch (keycap_line_reader_push(&line_reader, byte)) {
		case KEYCAP_LINE_READY:
			if (process_line(keys, keys_ready, lighting, agents,
					 agents_active, status_active,
					 line_reader.line)) {
				*last_host_command = k_uptime_get_32();
				*host_timed_out = false;
			}
			break;
		case KEYCAP_LINE_OVERFLOW:
			serial_write("ERROR line-too-long\n");
			break;
		case KEYCAP_LINE_NONE:
			break;
		}
	}
}

int main(void)
{
	struct neokey keys;
	char event_line[48];
	uint8_t stable = 0;
	uint8_t candidate = 0;
	uint8_t candidate_count = 0;
	uint32_t sequence = 0;
	uint32_t last_host_command = k_uptime_get_32();
	uint32_t last_hello_retry = k_uptime_get_32();
	bool host_timed_out = false;
	uint32_t last_lighting_frame = UINT32_MAX;
	struct keycap_gesture_detector gestures;
	struct keycap_lighting_profile lighting;
	enum keycap_agent_state agent_states[KEYCAP_LED_COUNT] = {
		KEYCAP_AGENT_EMPTY, KEYCAP_AGENT_EMPTY, KEYCAP_AGENT_EMPTY, KEYCAP_AGENT_EMPTY,
	};
	bool agents_active = false;
	bool status_active = true;
	keycap_gesture_init(&gestures);
	keycap_lighting_default(&lighting);
	keycap_line_reader_init(&line_reader);

	/* Console bring-up can fail after a debugger reset, before the board's
	 * serial bridge has re-enumerated. Returning here ends the main thread:
	 * the device goes permanently silent with the NeoKey holding whatever
	 * frame it last received, and only a power cycle recovers it. Retry
	 * instead, so a transient failure costs a moment rather than the session.
	 */
	while (serial_rx_start() != 0) {
		k_sleep(K_MSEC(250));
	}
	send_hello();
	while ((keycap_neokey_status =
			neokey_init(&keys, i2c, NEOKEY_ADDRESS)) != 0) {
		serial_write("ERROR neokey-init\n");
		/* Keep draining the receive ring between attempts. A blocking
		 * sleep here overflows the ring with the host's PING and
		 * KEEPALIVE traffic and desynchronizes the line protocol.
		 */
		for (uint32_t slice = 0; slice < NEOKEY_RETRY_SLICES; ++slice) {
			pump_serial(&keys, false, &lighting, agent_states,
				    &agents_active, &status_active,
				    &last_host_command, &host_timed_out);
			k_sleep(K_MSEC(NEOKEY_RETRY_SLICE_MS));
		}
	}
	serial_write("READY neokey 0x30\n");
	show_status(&keys, KEYCAP_STATUS_PAUSED, 0, NULL);
	/* Commands received while NeoKey was unavailable were deliberately
	 * acknowledged but could not be rendered. Re-announce readiness now so
	 * the host pushes the current status and lighting profile again. Without
	 * this handshake, a normal slow I2C start can leave all keys stuck on the
	 * paused/orange frame until the next unrelated UI state change.
	 */
	send_hello();

	while (true) {
		bool was_timed_out = host_timed_out;

		pump_serial(&keys, true, &lighting, agent_states, &agents_active,
			    &status_active, &last_host_command, &host_timed_out);
		if (was_timed_out && !host_timed_out) {
			/* The host is back. It only sends STATUS on a state change, so
			 * announce ourselves to make it push its current state instead of
			 * waiting for one that may never come.
			 */
			send_hello();
		}

		uint8_t sample;
		if (neokey_read_buttons(&keys, &sample) == 0) {
			if (sample != candidate) {
				candidate = sample;
				candidate_count = 1;
			} else if (candidate_count < DEBOUNCE_SAMPLES) {
				++candidate_count;
			}

			if (candidate_count == DEBOUNCE_SAMPLES && candidate != stable) {
				uint8_t changed = candidate ^ stable;
				stable = candidate;
				for (uint8_t key = 0; key < KEYCAP_LED_COUNT; ++key) {
					uint8_t bit = BIT(key);
					if ((changed & bit) != 0 &&
					    keycap_protocol_format_button(
						    event_line, sizeof(event_line), key + 1,
						    (stable & bit) != 0, ++sequence) > 0) {
						serial_write(event_line);
					}
				}
			}
		}

		uint32_t now = k_uptime_get_32();
		struct keycap_gesture_event events[KEYCAP_GESTURE_KEY_COUNT];
		size_t event_count = keycap_gesture_update(
			&gestures, stable, now, events, ARRAY_SIZE(events));
		for (size_t index = 0; index < event_count; ++index) {
			const char *name = events[index].type == KEYCAP_GESTURE_SHORT ? "SHORT" :
					   events[index].type == KEYCAP_GESTURE_LONG ? "LONG" :
					   "DOUBLE";
			if (keycap_protocol_format_gesture(event_line, sizeof(event_line),
						   events[index].key, name, ++sequence) > 0) {
				serial_write(event_line);
			}
		}

		/* The microphone is powered only while its effect is selected and the
		 * standby lane is actually visible. An approval overlay or agent
		 * status takes the keys back, and the microphone with them.
		 */
		bool audio_effect = lighting.mode == KEYCAP_LIGHTING_AUDIO ||
				    lighting.mode == KEYCAP_LIGHTING_SPECTRUM ||
				    lighting.mode == KEYCAP_LIGHTING_PITCH ||
				    lighting.mode == KEYCAP_LIGHTING_TEMPO;

		/* Touching the keypad is the wake gesture. The microphone is off
		 * while asleep, so it cannot hear its own way back.
		 */
		if (audio_asleep && stable != 0u) {
			audio_asleep = false;
		}

		bool wants_audio = audio_effect && !status_active && !agents_active &&
				   !audio_asleep;
		if (wants_audio != keycap_audio_is_running()) {
			if (wants_audio) {
				(void)keycap_audio_start();
			} else {
				keycap_audio_stop();
			}
		}
		uint32_t lighting_frame = now / KEYCAP_LIGHTING_FRAME_MS;
		if (lighting_frame != last_lighting_frame && !status_active) {
			struct keycap_rgb colors[KEYCAP_LED_COUNT];
			if (agents_active) {
				keycap_agent_render(agent_states, stable, now, colors);
			} else if (audio_effect && audio_asleep) {
				/* Nothing to visualise and no microphone running, so
				 * show a plain dim standby rather than a dark keypad.
				 */
				struct keycap_lighting_profile standby = lighting;

				standby.mode = KEYCAP_LIGHTING_RAINBOW;
				standby.brightness = lighting.brightness / 4u;
				keycap_lighting_render(&standby, stable, now, colors);
			} else if (audio_effect) {
				struct keycap_audio_frame frame;

				keycap_audio_get(&frame);
				if (frame.quiet) {
					/* Silent long enough that holding the microphone
					 * powered serves no one. Sleep until touched.
					 */
					audio_asleep = true;
				}
				if (lighting.mode == KEYCAP_LIGHTING_AUDIO) {
					keycap_audio_render(&lighting, frame.level, stable,
							    now, colors);
				} else if (lighting.mode == KEYCAP_LIGHTING_TEMPO) {
					keycap_tempo_render(&lighting, frame.level,
							    frame.beats, stable, colors);
				} else if (lighting.mode == KEYCAP_LIGHTING_PITCH) {
					keycap_pitch_render(&lighting, frame.level,
							    frame.pitch, stable, colors);
				} else {
					keycap_spectrum_render(&lighting, frame.band,
							       stable, colors);
				}
			} else {
				keycap_lighting_render(&lighting, stable, now, colors);
			}
			if (neokey_set_leds(&keys, colors) != 0) {
				keycap_neokey_status = -EIO;
			}
			last_lighting_frame = lighting_frame;
		}

		/* The fail-safe is held by host_timed_out alone. Latching
		 * status_active here would survive the host's return, because only a
		 * STATUS command clears it and the host sends those on state changes
		 * only -- leaving the keys amber on a healthy link.
		 */
		if (!host_timed_out &&
		    now - last_host_command >= HOST_WATCHDOG_MS) {
			host_timed_out = true;
			agents_active = false;
			/* Continue the last configured standalone lighting effect while
			 * asking the host to reconnect. Amber is reserved for an explicit
			 * PAUSED command; a sleeping Mac must not latch the keyboard there.
			 */
			status_active = false;
			send_hello();
			last_hello_retry = now;
		} else if (host_timed_out &&
			   now - last_hello_retry >= HOST_HELLO_RETRY_MS) {
			/* The first HELLO was emitted during the outage that tripped the
			 * watchdog, so it is the line most likely to have been lost.
			 * Keep asking until the host answers.
			 */
			send_hello();
			last_hello_retry = now;
		}
		k_sleep(K_MSEC(10));
	}
	return 0;
}

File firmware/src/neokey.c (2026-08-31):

/* SPDX-License-Identifier: Apache-2.0 */
#include "neokey.h"

#include <errno.h>
#include <string.h>
#include <zephyr/drivers/i2c.h>
#include <zephyr/kernel.h>

#define SEESAW_GPIO_BASE 0x01
#define SEESAW_GPIO_DIRCLR_BULK 0x03
#define SEESAW_GPIO_BULK 0x04
#define SEESAW_GPIO_BULK_SET 0x05
#define SEESAW_GPIO_PULLENSET 0x0b

#define SEESAW_NEOPIXEL_BASE 0x0e
#define SEESAW_NEOPIXEL_PIN 0x01
#define SEESAW_NEOPIXEL_SPEED 0x02
#define SEESAW_NEOPIXEL_BUF_LENGTH 0x03
#define SEESAW_NEOPIXEL_BUF 0x04
#define SEESAW_NEOPIXEL_SHOW 0x05

#define NEOKEY_PIXEL_PIN 3
#define NEOKEY_BUTTON_MASK 0x000000f0u
#define NEOKEY_PIXEL_BYTES (KEYCAP_LED_COUNT * 3)

static int write_register(const struct neokey *device, uint8_t module,
			  uint8_t function, const uint8_t *payload, size_t length)
{
	uint8_t frame[2 + 2 + NEOKEY_PIXEL_BYTES];

	if (length > sizeof(frame) - 2) {
		return -EMSGSIZE;
	}
	frame[0] = module;
	frame[1] = function;
	if (length > 0) {
		memcpy(frame + 2, payload, length);
	}
	return i2c_write(device->i2c, frame, length + 2, device->address);
}

static int read_register(const struct neokey *device, uint8_t module,
			 uint8_t function, uint8_t *payload, size_t length)
{
	uint8_t selector[] = {module, function};
	int result = i2c_write(device->i2c, selector, sizeof(selector), device->address);
	if (result != 0) {
		return result;
	}

	/* Seesaw processes the selector after the write transaction completes. */
	k_busy_wait(250);
	return i2c_read(device->i2c, payload, length, device->address);
}

static int configure_buttons(const struct neokey *device)
{
	uint8_t mask[] = {0x00, 0x00, 0x00, 0xf0};
	int result = write_register(device, SEESAW_GPIO_BASE,
				    SEESAW_GPIO_DIRCLR_BULK, mask, sizeof(mask));
	if (result == 0) {
		result = write_register(device, SEESAW_GPIO_BASE,
					SEESAW_GPIO_PULLENSET, mask, sizeof(mask));
	}
	if (result == 0) {
		result = write_register(device, SEESAW_GPIO_BASE,
					SEESAW_GPIO_BULK_SET, mask, sizeof(mask));
	}
	return result;
}

static int configure_pixels(const struct neokey *device)
{
	uint8_t speed = 1;
	uint8_t pin = NEOKEY_PIXEL_PIN;
	uint8_t length[] = {0x00, NEOKEY_PIXEL_BYTES};

	int result = write_register(device, SEESAW_NEOPIXEL_BASE,
				    SEESAW_NEOPIXEL_SPEED, &speed, 1);
	if (result == 0) {
		result = write_register(device, SEESAW_NEOPIXEL_BASE,
					SEESAW_NEOPIXEL_BUF_LENGTH, length,
					sizeof(length));
	}
	if (result == 0) {
		result = write_register(device, SEESAW_NEOPIXEL_BASE,
					SEESAW_NEOPIXEL_PIN, &pin, 1);
	}
	return result;
}

int neokey_init(struct neokey *device, const struct device *i2c, uint8_t address)
{
	if (device == NULL || i2c == NULL || !device_is_ready(i2c)) {
		return -ENODEV;
	}
	device->i2c = i2c;
	device->address = address;

	int result = configure_pixels(device);
	if (result == 0) {
		result = configure_buttons(device);
	}
	if (result == 0) {
		const struct keycap_rgb off[KEYCAP_LED_COUNT] = {0};
		result = neokey_set_leds(device, off);
	}
	return result;
}

int neokey_read_buttons(const struct neokey *device, uint8_t *pressed_mask)
{
	uint8_t bytes[4];
	int result = read_register(device, SEESAW_GPIO_BASE, SEESAW_GPIO_BULK,
				   bytes, sizeof(bytes));
	if (result != 0) {
		return result;
	}

	uint32_t pins = ((uint32_t)bytes[0] << 24) |
			((uint32_t)bytes[1] << 16) |
			((uint32_t)bytes[2] << 8) | bytes[3];
	*pressed_mask = (uint8_t)(((pins ^ NEOKEY_BUTTON_MASK) &
				      NEOKEY_BUTTON_MASK) >> 4);
	return 0;
}

int neokey_set_leds(const struct neokey *device,
		    const struct keycap_rgb colors[KEYCAP_LED_COUNT])
{
	uint8_t payload[2 + NEOKEY_PIXEL_BYTES] = {0x00, 0x00};

	for (size_t index = 0; index < KEYCAP_LED_COUNT; ++index) {
		/* NeoKey pixels are GRB. Cap brightness at 25% for a desk device. */
		payload[2 + index * 3] = colors[index].green >> 2;
		payload[3 + index * 3] = colors[index].red >> 2;
		payload[4 + index * 3] = colors[index].blue >> 2;
	}

	int result = write_register(device, SEESAW_NEOPIXEL_BASE,
				    SEESAW_NEOPIXEL_BUF, payload, sizeof(payload));
	if (result == 0) {
		result = write_register(device, SEESAW_NEOPIXEL_BASE,
					SEESAW_NEOPIXEL_SHOW, NULL, 0);
	}
	return result;
}

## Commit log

2026-08-31 Add audio-reactive lighting effects
    Three standby effects driven by the board's own PDM microphone, sharing a
    single capture and a single pass over each frame:
    AUDIO the four keys become one level meter, sharing a colour that
    cycles the rainbow at the profile speed
    SPECTRUM each key takes its own frequency band and its own colour,
    bass on key one through treble on key four
    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
2026-08-31 Sleep the microphone when nothing is playing
    A selected audio effect held the microphone powered for as long as the keypad
    was switched on, whether or not anything was playing. After about ten minutes
    without sound the device now switches the regulator off, falls back to a dim
    standby effect, and waits; a key press or a fresh LIGHTING command wakes it.
    Choosing an audio effect therefore powers the microphone while there is music
    rather than all day.
    Silence is judged by how much dynamic range the signal has relative to its own
    noise floor, not by an absolute level. Every room has its own noise, and a
    fixed threshold would never fire in one room and fire constantly in another;
    measured here,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
    [main.c]
2026-08-31 Add a lighting effect whose colour advances with the beat
    TEMPO fills the keys with loudness exactly as AUDIO does, but takes its hue
    from the beat count rather than the clock, stepping an eighth of the wheel on
    every bass transient. A full turn is eight beats, two bars of four, so the
    colour returns to where it started on a musical boundary while a slow track
    drifts and a fast one races.
    A beat is bass that is clear of its own noise floor, above its own rolling
    average, and rising against the previous frame. The rise is the part that
    matters and the part that was missing first time: a sustained bass note sits
    above its own average for as long as it lasts, and counted nineteen beats
    across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
    [main.c]
2026-09-01 Add the parametric CAD sources for the desktop housing
    The firmware and host code have been in the repo since the initial release,
    but the enclosure they run inside existed only on this machine. Anyone
    building one had no case, and the board dimensions the design depends on were
    recorded nowhere a reader could check.
    The housing is two printed pieces: a tray holding a Seeed XIAO Sense in a
    cavity underneath, and a plate carrying an Adafruit NeoKey 1x4 QT above it.
    Because the NeoKey has Kailh hot-swap sockets, this is built as a real
    keyboard plate rather than a lid - switches drop through 14 mm cutouts and
    their pins press into the sockets, which is what ties the PCB to the plate, so
    the c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
    [keycap_case.step, neokey_1x4_qt_4980.step, plate.3mf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]
